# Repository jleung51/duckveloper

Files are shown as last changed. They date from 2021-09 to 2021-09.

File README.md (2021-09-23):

# Duckveloper 🐤

<a href="https://www.youtube.com/watch?v=De-VEcLn2f4">
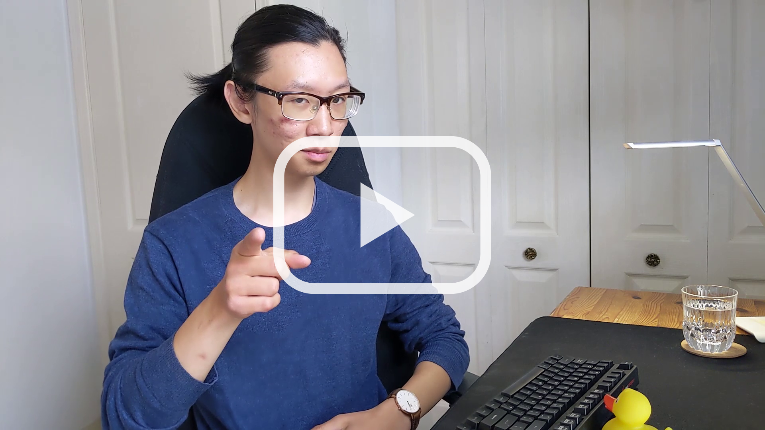
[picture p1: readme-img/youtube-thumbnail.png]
  
</a>

---

Say goodbye to the low-tech days of rubber duck debugging! **Duckveloper 🐤** is the coding partner you never knew you needed.

Simply press a button and the innovative, high-tech duck will generously provide you with words of "encouragement" to help you figure out what's really wrong with your code.

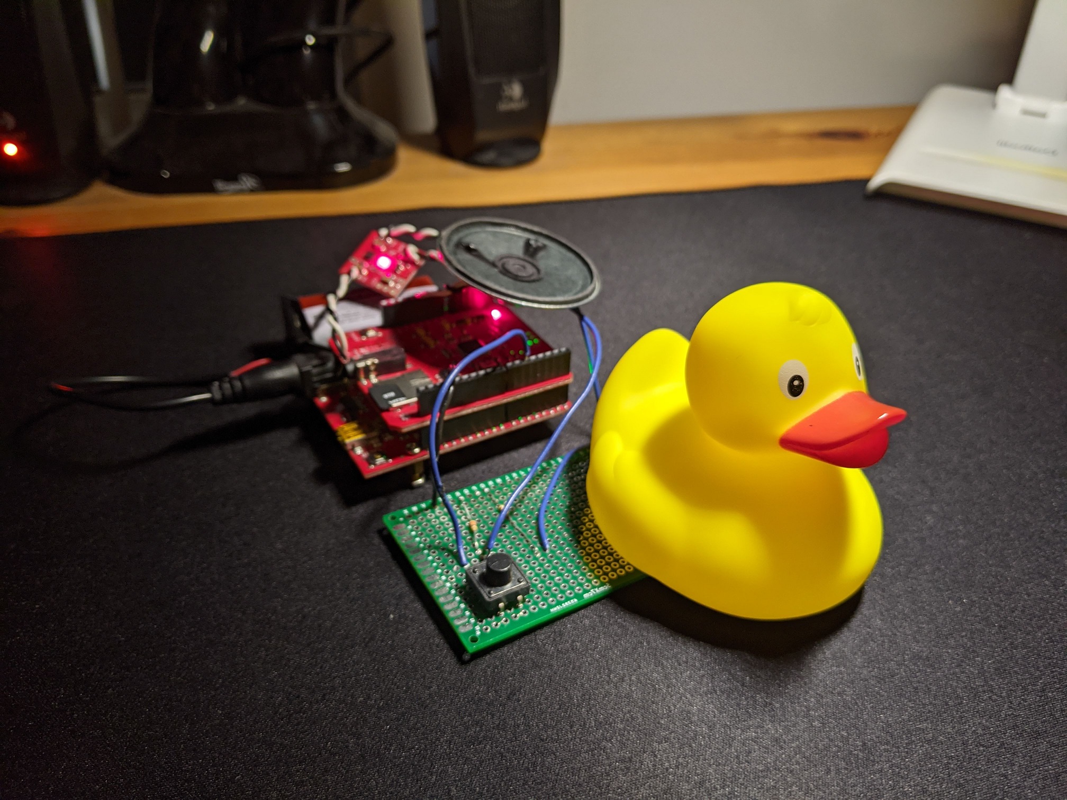
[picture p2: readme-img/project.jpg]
Picture of project


Arduino project with an MP3 shield, speaker, and rubber duck. Inspired by the strategy of [rubber duck debugging](https://en.wikipedia.org/wiki/Rubber_duck_debugging).

## Components

This project uses the [Arduino VS1053 Library](https://github.com/mpflaga/Arduino_Library-vs1053_for_SdFat) to decode MP3 audio and interface with the MP3 shield.

Serial | Name | Quantity | Description
--- | --- | --- | ---
| 🐤 | Rubber Duck | As many as you need to be happy in life
DEV-11021 | [Arduino Uno - R3](https://www.sparkfun.com/products/11021) | 1
DEV-12660 | [SparkFun MP3 Player Shield](https://www.sparkfun.com/products/12660) | 1 | Requires soldering on headers
PRT-11417 | [Arduino Stackable Header Kit - R3](https://www.sparkfun.com/products/11417) | 1 | For the MP3 Shield
BOB-11044 | [SparkFun Mono Audio Amp Breakout - TPA2005D1](https://www.sparkfun.com/products/11044) | 1 | Requires soldering connections
COM-09151 | [Speaker (0.5W)](https://www.sparkfun.com/products/9151) | 1
PRT-10512 | Optional: [9V Battery Holder](https://www.sparkfun.com/products/10512) | 1

Other common generic components you should have:
* 1 button/switch (e.g. [Momentary Pushbutton Switch](https://www.sparkfun.com/products/9190))
* 1 LED, bright enough to shine through the duck's plastic (e.g. [Super Bright LED](https://www.sparkfun.com/products/11118))
* 1 breadboard
* Resistors (1 x 330 Ω, 1 x 10k Ω)
* Wires

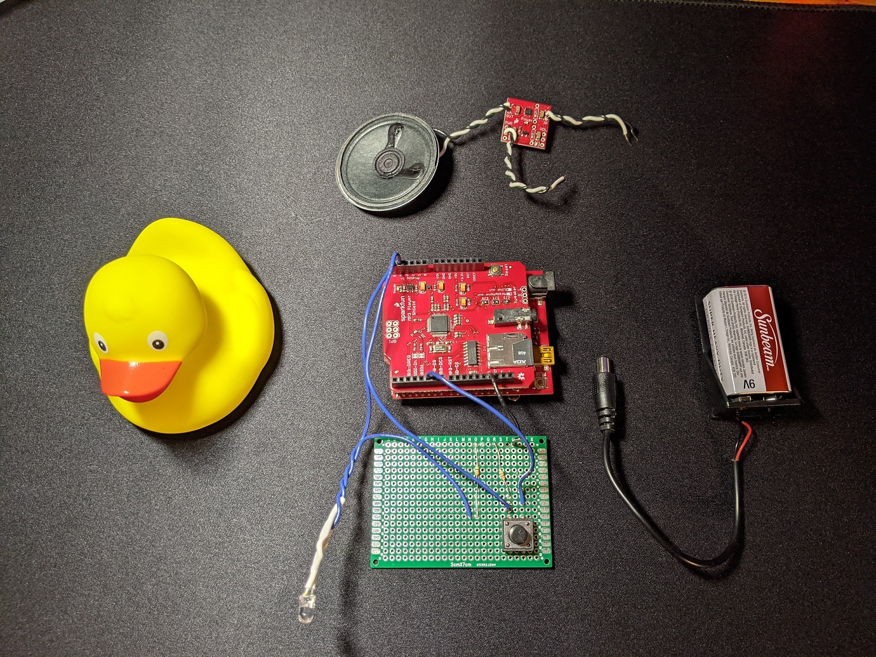
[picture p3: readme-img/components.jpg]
Picture of components


## Setup

### Hardware Configuration

Solder the stackable headers onto the MP3 Player shield.

Mount the MP3 Player shield onto the Arduino Uno.

Connect the remaining components according to the following schematic:
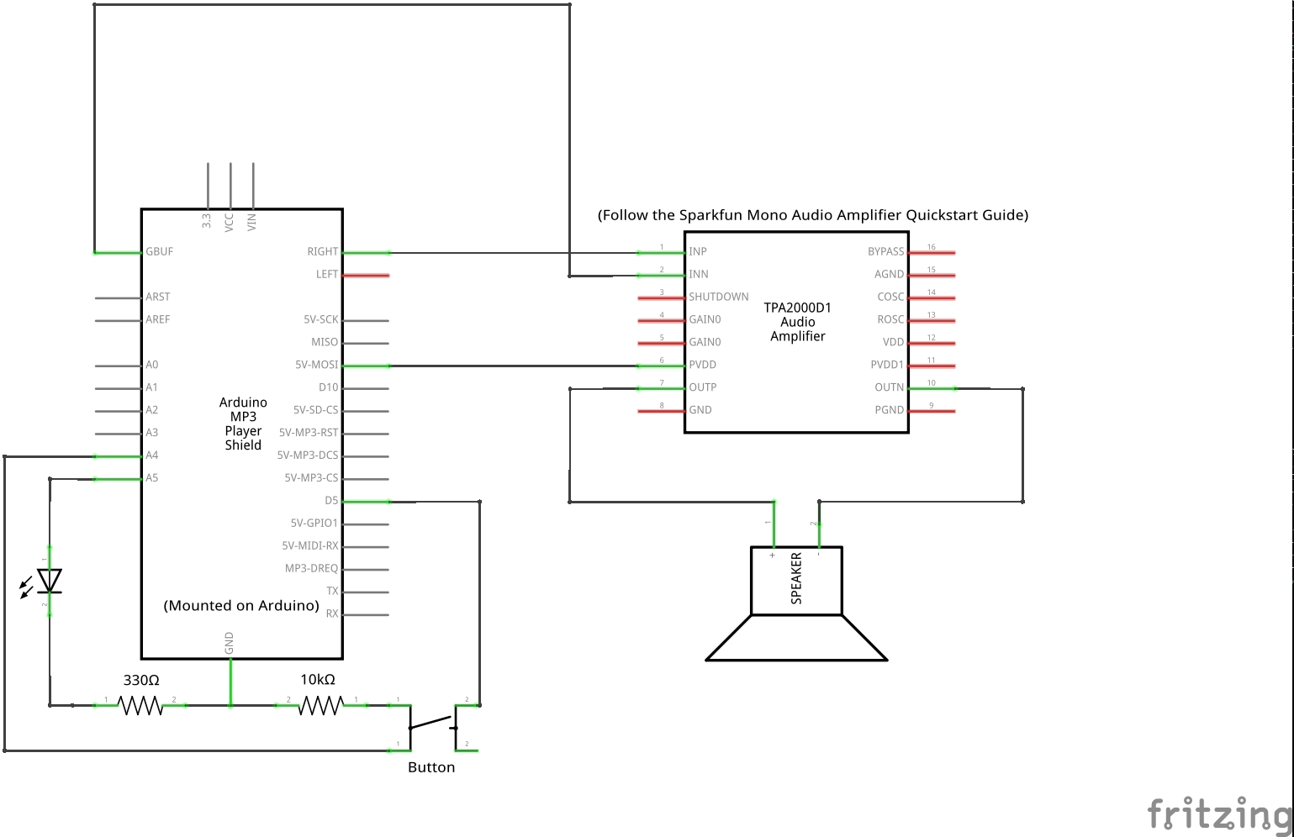
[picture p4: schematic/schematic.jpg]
Schematic


To accurately connect the Audio Breakout Board (TPA2005D1), follow the [SparkFun Mono Audio Amplifier Quickstart Guide](https://www.sparkfun.com/tutorials/392).

### Duck Configuration

Use a hobby or utility knife to (carefully!) cut a small hole in the duck's rear end.

Insert the LED into the hole so it will light up the duck when a voiceline is playing.

 Apologize profusely throughout the procedure.

### SD Card Setup

Format the SD card to FAT16 or FAT32.

Place your intended voicelines onto the SD card, named in the format of `track001.mp3`, `track002.mp3`, etc.

Install the SD card into the MP3 Player Shield.

### Software Configuration

[Download the Arduino IDE](https://www.arduino.cc/en/software).

[Install the VS1053 library in the Arduino IDE](https://mpflaga.github.io/Arduino_Library-vs1053_for_SdFat/).

Open the `duckveloper/duckveloper.ino` program. Modify the value `NUMBER_OF_TRACKS` ([location in code here](https://github.com/jleung51/duckveloper/blob/0c18382fe2e1356997615a03e70b01add00e2793/duckveloper/duckveloper.ino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)) accordingly, if you have changed the number of voicelines on the SD card.

Compile and upload the project to the Arduino.

### Operating the Project

Press the button to trigger one of the random voicelines as well as the LED.

To monitor the program's output, open the serial monitor and set the baud rate to 115200.

## Reference

For more information on working with the components in this project, see:
* [SparkFun MP3 Player Shield Hookup Guide](https://learn.sparkfun.com/tutorials/mp3-player-shield-hookup-guide-v15/all)
* [SparkFun Mono Audio Amplifier Quickstart Guide](https://www.sparkfun.com/tutorials/392)

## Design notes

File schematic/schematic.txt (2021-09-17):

D5 -> Button -> A4
             -> 10k Ohm resistor - > GND

A5 -> LED  -> 330 Ohm resistor -> GND

5V -> Audio Amplifier PWR -> GND

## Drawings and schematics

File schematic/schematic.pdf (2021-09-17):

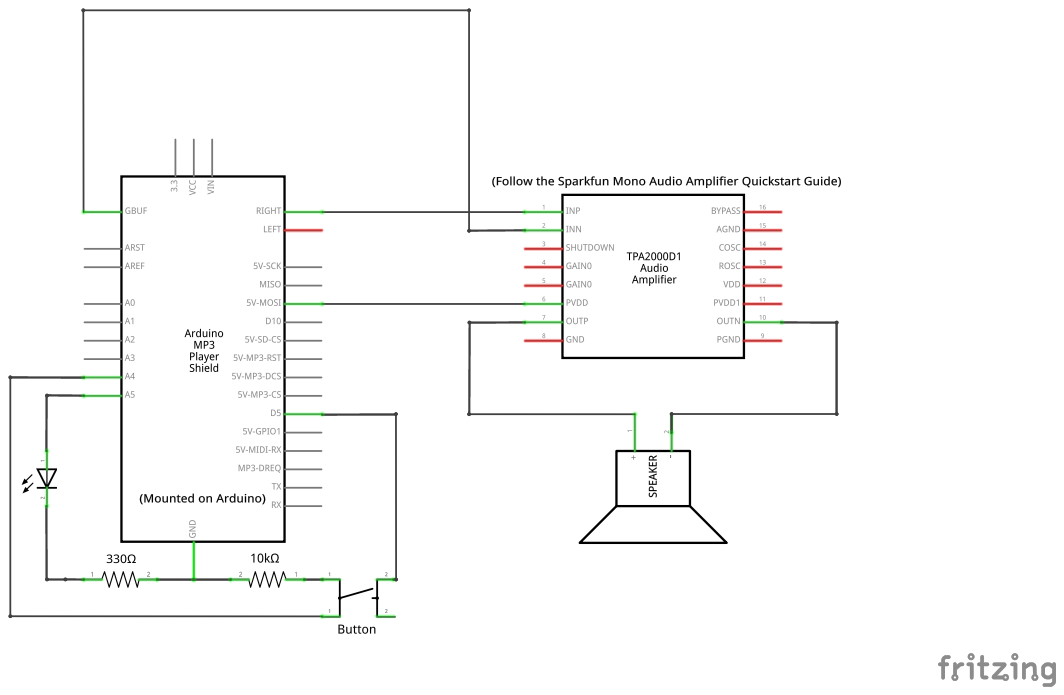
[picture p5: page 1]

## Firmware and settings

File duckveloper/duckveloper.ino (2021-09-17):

/**
 * This Arduino sketch lights up an LED and plays a random MP3 track from an
 * SD card when a button is pressed.
 *
 * The SD card must be loaded onto the Arduino using a shield or other
 * component.
 * Each MP3 track must be named sequentially in the format track001.mp3,
 * track002.mp3, etc.
 *
 */

#include <SPI.h>
#include <FreeStack.h>
#include <SdFat.h>
#include <vs1053_SdFat.h>


// Below is not needed if interrupt driven. Safe to remove if not using.
#if defined(USE_MP3_REFILL_MEANS) && USE_MP3_REFILL_MEANS == USE_MP3_Timer1
  #include <TimerOne.h>
#elif defined(USE_MP3_REFILL_MEANS) && USE_MP3_REFILL_MEANS == USE_MP3_SimpleTimer
  #include <SimpleTimer.h>
#endif



// ------------------------------------------
// HARDWARE SETTINGS
// ------------------------------------------

// According to the SparkFun MP3 Player Shield Hookup Guide:
// https://learn.sparkfun.com/tutorials/mp3-player-shield-hookup-guide-v15/all
// The available pins are:
//   The hardware UART pins -- RX and TX -- on pins 0 and 1
//   D5 and D10 (PWM pins)  -- NOTE: Using D10 causes my board to freeze while playing any track. Buyer beware.
//   All analog pins (A0 through A5)

// See the schematic/ directory for instructions on connecting the components.

// Pin connections

const uint8_t PIN_LED = A5;
const uint8_t PIN_BTN_PWR = 5;
const uint8_t PIN_BTN_READ = A4;

// Used for generating a random seed for the RNG
// Choose any unconnected analog pin
const uint8_t PIN_ANALOG_RNG = A0;



// ------------------------------------------
// GLOBAL VARIABLES
// ------------------------------------------

// Total number of MP3 tracks on the SD card.
const uint8_t NUMBER_OF_TRACKS = 5;
uint8_t last_played = 9999;

// Instances of the libraries
SdFat sd;
vs1053 MP3player;



// ------------------------------------------
// FUNCTION PROTOTYPES
// ------------------------------------------

void seed_rng();

void set_volume_max();
void set_volume_min();
void set_volume(uint8_t decibels);

void play_track(uint8_t track_num);
void display_track_info();



// ------------------------------------------
// ARDUINO FUNCTIONS
// ------------------------------------------

void setup() {

  Serial.begin(115200);

  // Returned error codes are typically passed up from MP3player,
  // which in turn creates and initializes the SdCard objects
  Serial.println(F("To look up error codes, navigate to: https://mpflaga.github.io/Arduino_Library-vs1053_for_SdFat/index.html#Error_Codes"));

  // Display hardware information
  Serial.print(F("F_CPU = "));
  Serial.println(F_CPU);
  Serial.print(F("Free RAM = ")); // Available in Version 1.0 F() bases the string to into Flash, to use less SRAM.
  Serial.print(FreeStack(), DEC);  // Provided by SdFat
  Serial.println(F(" Should be a base line of 1028, on ATmega328 when using INTx"));

  // Initialize the SdCard
  if(!sd.begin(SD_SEL, SPI_FULL_SPEED)) {
    sd.initErrorHalt();
  }
  // Dsepending upon your SdCard environment, SPI_HAVE_SPEED may work better
  if(!sd.chdir("/")) {
    sd.errorHalt("sd.chdir");
  }

  // Initialize the MP3 Player Shield
  uint8_t result = MP3player.begin();
  if(result != 0) {
    Serial.print(F("Error code: "));
    Serial.print(result);
    Serial.println(F(" when trying to start MP3 player"));
    if( result == 6 ) {
      Serial.println(F("Warning: patch file not found, skipping."));
    }
  }

#if defined(__BIOFEEDBACK_MEGA__) // or other reasons, of your choosing.
  // Typically not used by most shields, hence commented out.
  Serial.println(F("Applying ADMixer patch."));
  if(MP3player.ADMixerLoad("admxster.053") == 0) {
    Serial.println(F("Setting ADMixer Volume."));
    MP3player.ADMixerVol(-3);
  }
#endif

  seed_rng();

  set_volume_max();


  // LED and button setup

  pinMode(PIN_LED, OUTPUT);
  digitalWrite(PIN_LED, LOW);

  pinMode(PIN_BTN_PWR, OUTPUT);
  digitalWrite(PIN_BTN_PWR, HIGH);

  pinMode(PIN_BTN_READ, INPUT);

}  // End of setup()


// Main loop of the program
void loop() {

// Below is only needed if not interrupt driven. Safe to remove if not using.
#if defined(USE_MP3_REFILL_MEANS) \
    && ( (USE_MP3_REFILL_MEANS == USE_MP3_SimpleTimer) \
    ||   (USE_MP3_REFILL_MEANS == USE_MP3_Polled)      )

  MP3player.available();
#endif

  // Upon button press:
  uint8_t buttonState = digitalRead(PIN_BTN_READ);
  if (buttonState == HIGH) {

    Serial.println(F("Button status: Pressed"));

    // Turn on light
    digitalWrite(PIN_LED, HIGH);

    // Select and play a random track (different from the previous)
    uint8_t track_num;
    do {
      track_num = random(1, NUMBER_OF_TRACKS+1);
    } while (track_num == last_played);
    last_played = track_num;

    play_track(track_num);

    // Wait until track ends
    do {
      delay(100);
    } while (MP3player.isPlaying());
    Serial.println(F("Track finished"));

    // When done, turn off light
    digitalWrite(PIN_LED, LOW);

  } else {
    Serial.println(F("Button status: Not pressed"));
  }

  delay(100);
}



// ------------------------------------------
// CUSTOM FUNCTIONS
// ------------------------------------------

// This function seeds the random number generator with a partially random value.
void seed_rng() {
  randomSeed(analogRead(PIN_ANALOG_RNG));
}

// This function maximizes the volume of the MP3 shield.
void set_volume_max() {
    set_volume(2);
}

// This function minimizes the volume of the MP3 shield.
void set_volume_min() {
    set_volume(254);
}

// This function sets the volume of the MP3 shield to a certain level.
//
// Note that dB is negative.
void set_volume(uint8_t decibels) {
  MP3player.setVolume(decibels, decibels);

  Serial.print(F("Volume changed to -"));
  Serial.print(decibels>>1, 1);
  Serial.println(F("[dB]"));
}

// This function plays a track numbered as "track00[track_num].mp3".
//
// Throws an error if the track number is invalid (based on the value
// from NUMBER_OF_TRACKS).
void play_track(uint8_t track_num) {

#if USE_MULTIPLE_CARDS
  sd.chvol();  // Assign desired sdcard's volume
#endif

  // Validate that the track number is valid
  if (track_num > NUMBER_OF_TRACKS) {
    Serial.print(F("Error: Track "));
    Serial.print(track_num);
    Serial.print(" is invalid; there are a maximum of ");
    Serial.print(NUMBER_OF_TRACKS);
    Serial.println(" tracks.");
    return;
  }

  Serial.print(F("Playing track \"track00"));
  Serial.print(track_num);
  Serial.println(F(".mp3\""));
  uint8_t result = MP3player.playTrack(track_num);

  // Error codes reference:
  // https://mpflaga.github.io/Arduino_Library-vs1053_for_SdFat/index.html#Error_Codes
  if(result != 0) {
    Serial.print(F("VS1053 Error Code "));
    Serial.print(result);
    Serial.print(F(" when trying to play track "));
    Serial.println(track_num);
    return;
  }

  // display_track_info();
}


// This function displays the title, artist, and album of the current track.
void display_track_info() {

  if (MP3player.getState() != playback) {
    Serial.println(F("No track currently playing."));
  }

  char title[30];
  MP3player.trackTitle((char*)&title);

  char artist[30];
  MP3player.trackArtist((char*)&artist);

  char album[30];
  MP3player.trackAlbum((char*)&album);

  Serial.print(F("Playing "));
  Serial.write((byte*)&title, 30);
  Serial.print(F(" by "));
  Serial.write((byte*)&artist, 30);
  Serial.print(F(" from album "));
  Serial.write((byte*)&album, 30);

  Serial.println();
}

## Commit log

2021-08-01 Write track selection logic
2021-08-03 Add light and button functionality
2021-08-05 Add schematic and setup/operation instructions
    [duckveloper.fzz]
2021-09-15 Modify pins to avoid using D6
    Schematic will be updated in next commit.
    [duckveloper.ino]
2021-09-15 Update schematic (see last commit for changes)
    [duckveloper.fzz]
2021-09-16 Add warnings and conditionals per board
2021-09-16 Add function prototypes
2021-09-17 Change button-read pin to A4
    Use of D10 seems to be freezing up the board whenever any file is
    played.
2021-09-17 Update schematic (see previous commit)
    This replaces pin D10 with A4 for the button-read functionality.
    [duckveloper.fzz]
2021-09-17 Amplify track volumes
